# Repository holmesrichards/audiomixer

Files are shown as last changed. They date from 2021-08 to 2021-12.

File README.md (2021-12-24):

# Analog Output Audio Mixer

This is an audio mixer synth module in Kosmo format. It has three inputs, each with a slide attenuator, and a general level control and two identical outputs.

## Current draw
4 mA +12 V, 4 mA -12 V

## Photos

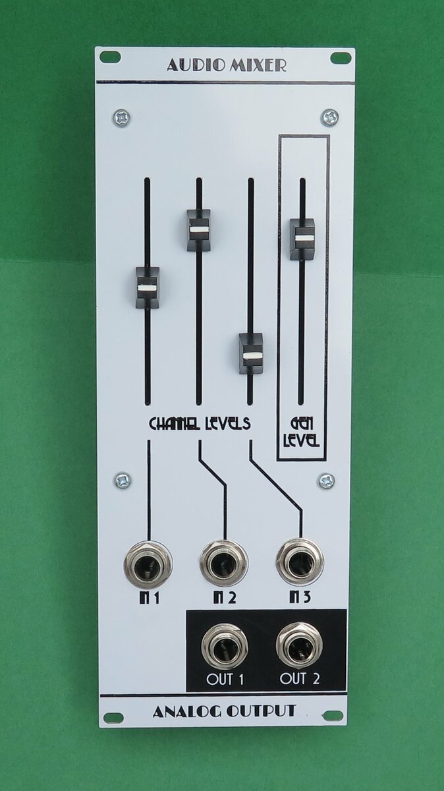
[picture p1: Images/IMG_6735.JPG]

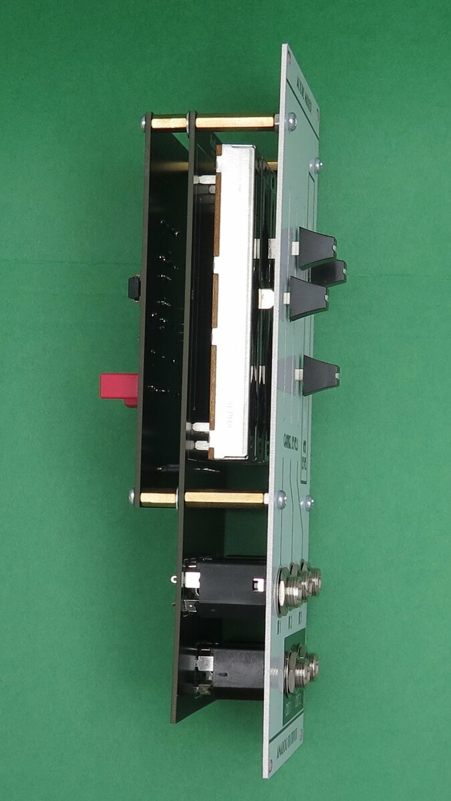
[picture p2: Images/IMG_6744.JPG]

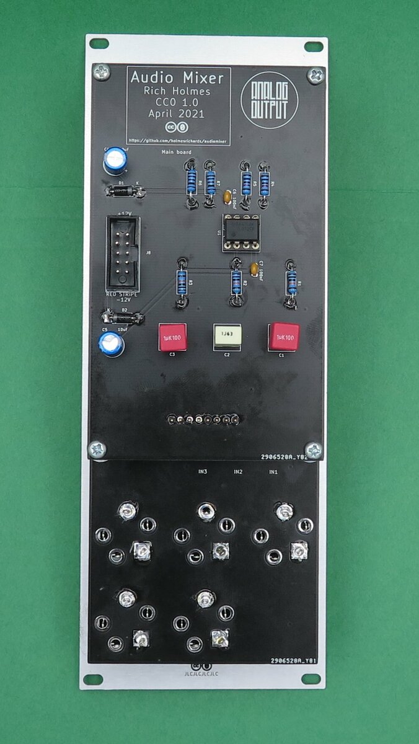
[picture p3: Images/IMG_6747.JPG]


## Documentation:

* [Schematic](Docs/ao_audio_mixer.pdf)
* [PCB layout](Docs/ao_audio_mixer_layout.pdf)
* [BOM](Docs/ao_audio_mixer_bom.md)
* [Build notes](Docs/build.md)

## GitHub repository

* [https://github.com/holmesrichards/audiomixer](https://github.com/holmesrichards/audiomixer)

## Submodules

This repo uses submodules aoKicad and Kosmo_panel, which provide needed libaries for KiCad. To clone:

```
git clone git@github.com:holmesrichards/audiomixer.git
git submodule init
git submodule update
```

Alternatively do

```
git clone --recurse-submodules git@github.com:holmesrichards/audiomixer.git
```

Or if you download the repository as a zip file, you must also click on the "aoKicad" and "Kosmo\_panel" links on the GitHub page (they'll have "@ something" after them) and download them as separate zip files which you can unzip into this repo's aoKicad and Kosmo\_panel directories.

If desired, copy the files from aoKicad and Kosmo\_panel to wherever you prefer (your KiCad user library directory, for instance, if you have one). Then in KiCad, add symbol libraries 

```
aoKicad/ao_symbols
Kosmo_panel/Kosmo
```
and footprint libraries 
```
aoKicad/ao_tht
Kosmo_panel/Kosmo_panel.
```

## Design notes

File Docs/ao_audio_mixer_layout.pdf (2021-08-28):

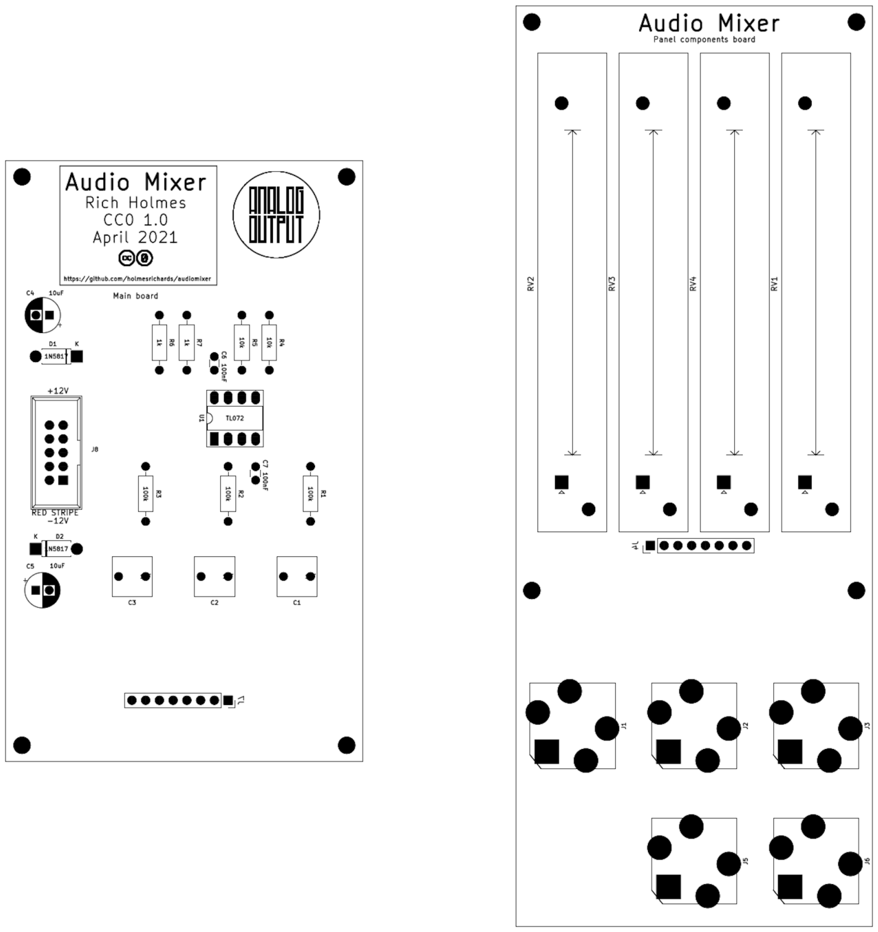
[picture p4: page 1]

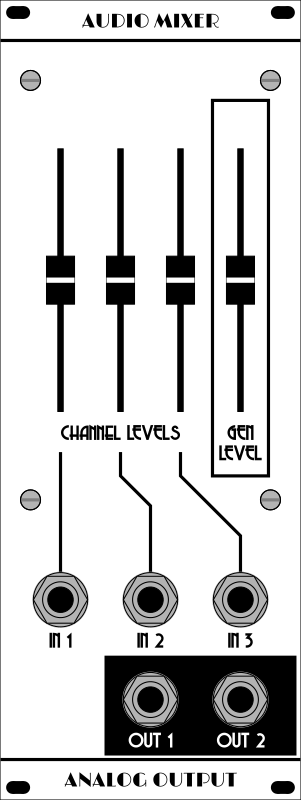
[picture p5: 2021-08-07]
Images/ao_audio_mixer_panel_slide.png

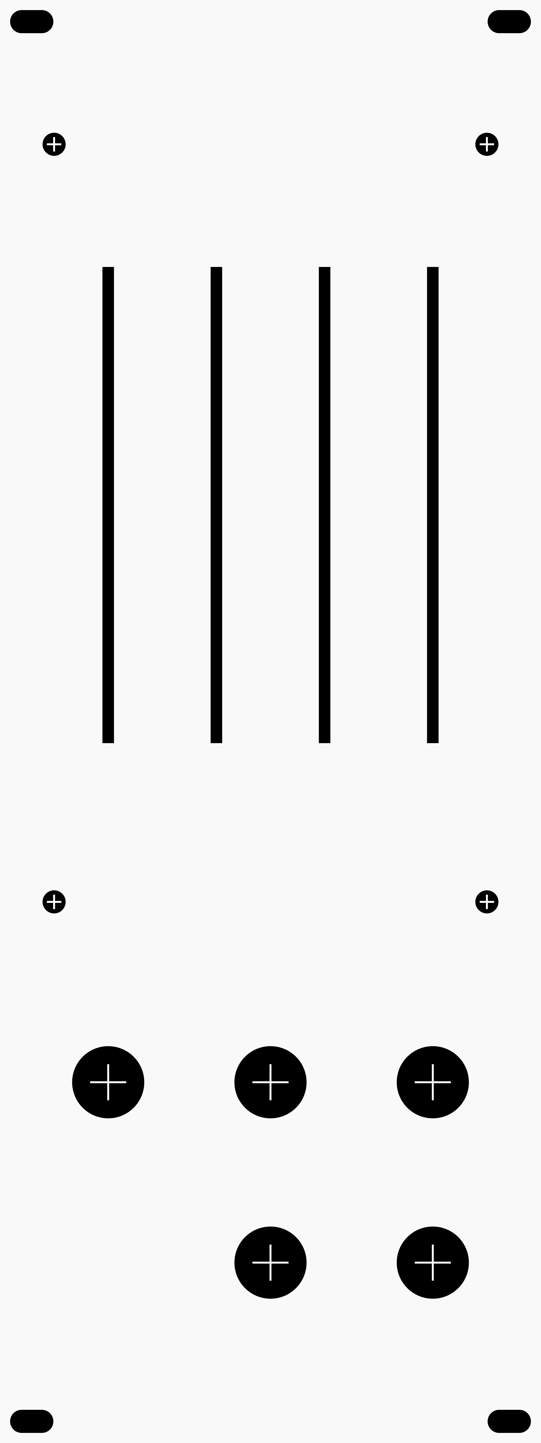
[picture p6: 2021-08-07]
Images/ao_audio_mixer_panel_slide_holes.png

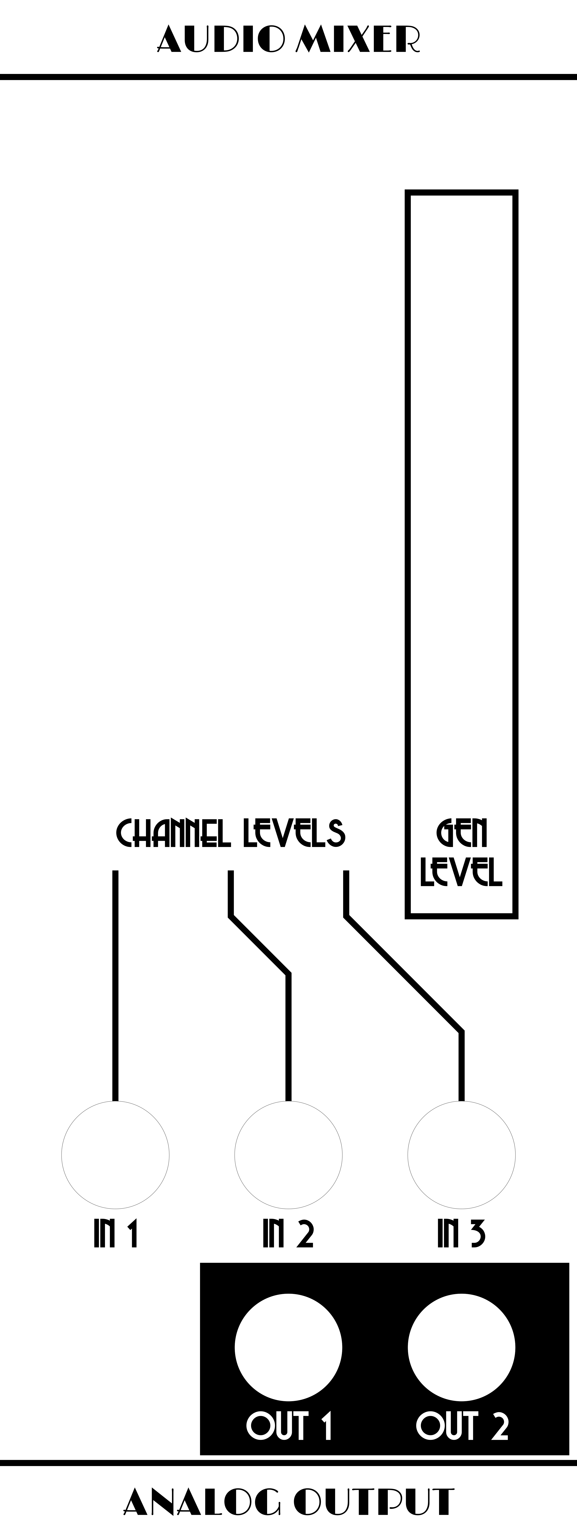
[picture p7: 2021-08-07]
Images/ao_audio_mixer_panel_slide_art.png

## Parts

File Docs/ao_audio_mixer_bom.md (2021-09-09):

# ao_audio_mixer.sch BOM

Sat 28 Aug 2021 09:02:02 AM EDT

Generated from schematic by Eeschema 5.1.10-88a1d61d58~90~ubuntu20.04.1

**Component Count:** 29

| Refs | Qty | Component | Description | Manufacturer | Part | Vendor | SKU |
| ----- | --- | ---- | --- | ---- | ---- | ---- | ---- |
| C1, C2, C3 | 3 | 1uF | Film capacitor |  |  | Tayda | A-4168 |
| C4, C5 | 2 | 10uF | Electrolytic capacitor |  |  | Tayda | A-4349 |
| C6, C7 | 2 | 100nF | Ceramic capacitor |  |  | Tayda | A-553 |
| D1, D2 | 2 | 1N5817 | Schottky diode |  |  | Tayda | A-159 |
| J1, J2, J3, J5, J6 | 5 | AudioJack2 | Audio Jack, 2 Poles (Mono / TS) |  |  | Tayda | A-1121 |
| J4 | 1 | Conn_01x08 | Pin socket 2.54 mm 1x8 |  |  |  |  |
| J7 | 1 | Conn_01x08 | Pin header 2.54 mm 1x8 |  |  |  |  |
| J8 | 1 | Synth_power_2x5 | Pin header 2.54 mm 2x5 |  |  | Tayda | A-2939 |
| R1, R2, R3 | 3 | 100k | Resistor |  |  |  |  |
| R4, R5 | 2 | 10k | Resistor |  |  |  |  |
| R6, R7 | 2 | 1k | Resistor |  |  |  |  |
| RV1, RV2, RV3, RV4 | 4 | A100k | Slide pot | Alpha | RA6020F | Tayda | A-4496 |
| U1 | 1 | TL072 | Dual op amp |  |  | Tayda | A-037 |
| | 1 | | 8 pin DIP socket | | | Tayda | A-001 |
| | 4 | | Slide pot shaft caps | | | | |
| | 4 sets | M3x12 mm | Screws and spacers (see [build notes](Docs/build.md)) | | |  |  |

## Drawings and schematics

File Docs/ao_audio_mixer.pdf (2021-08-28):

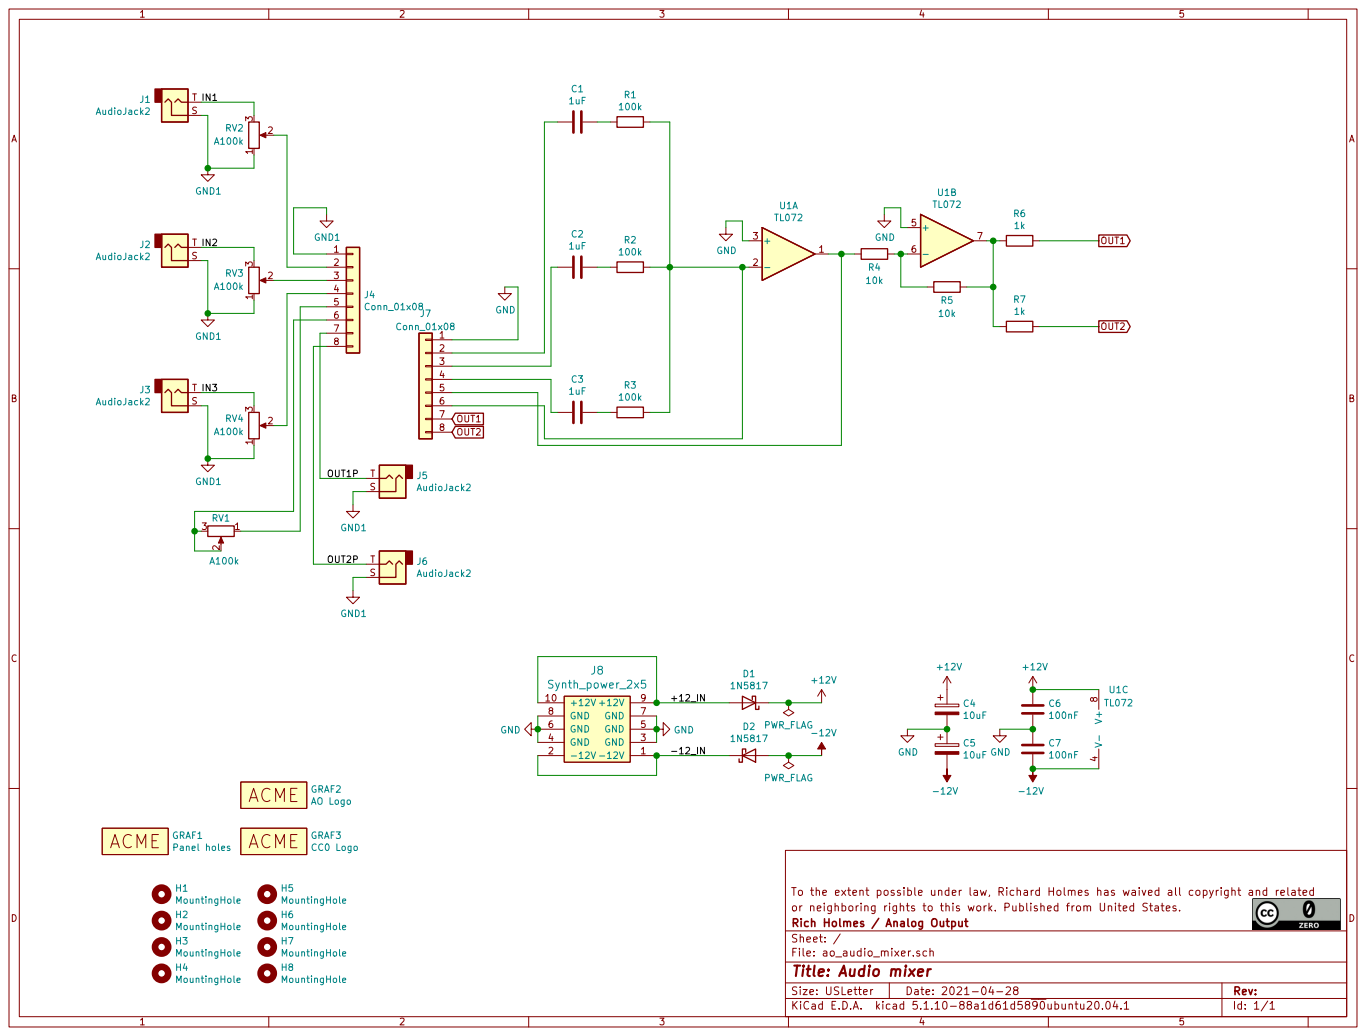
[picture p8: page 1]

3 RV3 A100k ACME GRAF1 Panel holes ACME GRAF3 CC0 Logo

To the extent possible under law, Richard Holmes has waived all copyright and related
or neighboring rights to this work. Published from United States.
File: ao_audio_mixer.sch Sheet: / Rich Holmes / Analog Output

Id: 1/1 Title: Audio mixer

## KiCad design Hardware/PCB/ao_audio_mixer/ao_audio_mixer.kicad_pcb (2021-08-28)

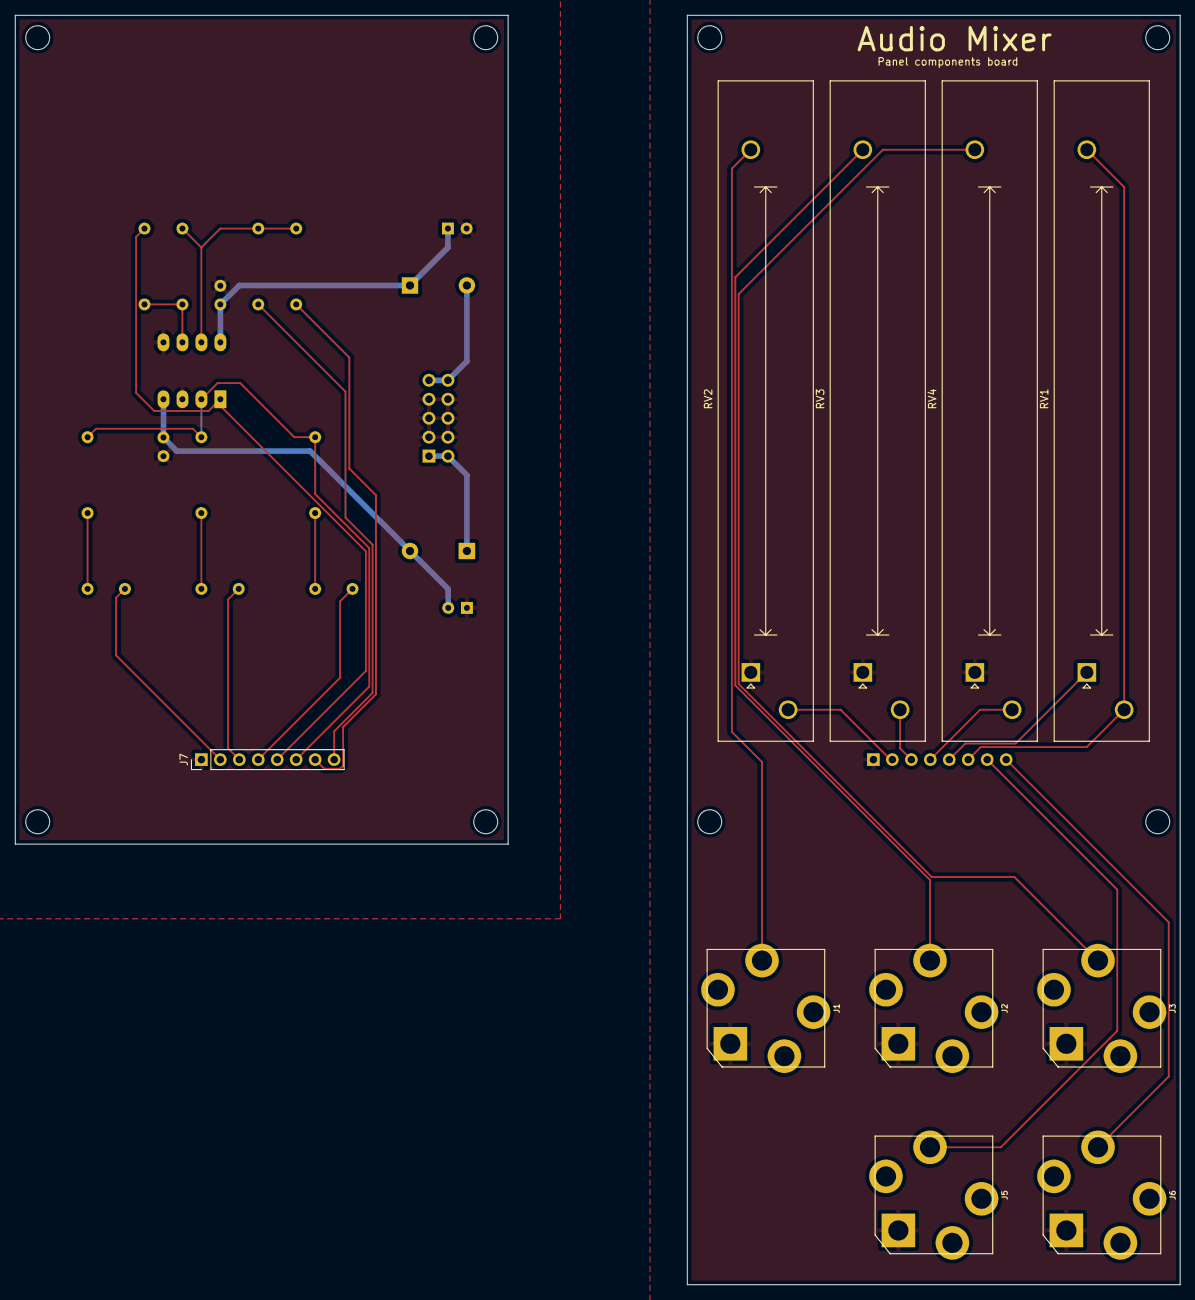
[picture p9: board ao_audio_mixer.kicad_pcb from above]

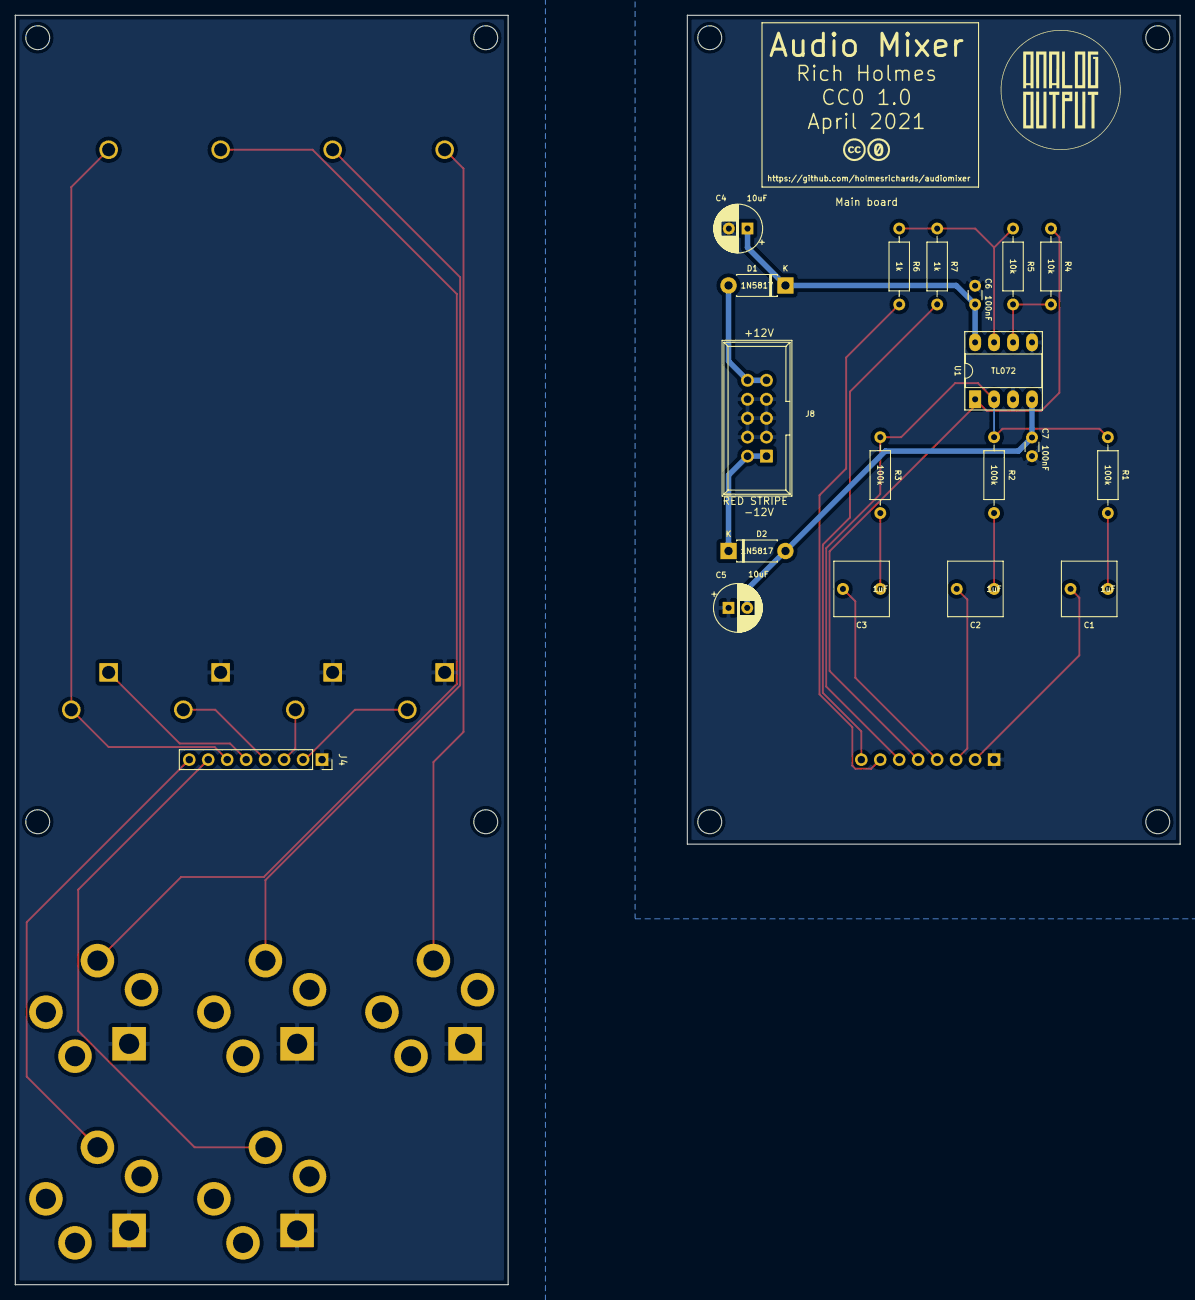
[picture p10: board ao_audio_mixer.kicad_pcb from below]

Board: 2 copper layers, 156.0 x 170.0 mm, 41 parts (25 on the bottom side), 28 nets.

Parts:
C1, C2, C3: 1uF; C_Rect_L7.2mm_W7.2mm_P5.00mm_FKS2_FKP2_MKS2_MKP2
C4, C5: 10uF; CP_Radial_D6.3mm_P2.50mm
C6, C7: 100nF; C_Disc_D3.0mm_W1.6mm_P2.50mm
D1, D2: 1N5817; D_DO-41_SOD81_P7.62mm_Horizontal
GRAF1, GRAF1#2: Panel holes; ao_audio_mixer_panel_slide_holes
GRAF2: AO Logo; analogoutput
GRAF3: CC0 Logo; CC0_logo
H1, H2, H3, H4, H5, H6, H7, H8: MountingHole; MountingHole_3.2mm_M3
J1, J2, J3, J5, J6: AudioJack2; Jack_6.35mm_PJ_629HAN
J4: Conn_01x08; PinSocket_1x08_P2.54mm_Vertical
J7: Conn_01x08; PinHeader_1x08_P2.54mm_Vertical
J8: Synth_power_2x5; Power_Header
R1, R2, R3: 100k; R_Axial_DIN0207_L6.3mm_D2.5mm_P10.16mm_Horizontal
R4, R5: 10k; R_Axial_DIN0207_L6.3mm_D2.5mm_P10.16mm_Horizontal
R6, R7: 1k; R_Axial_DIN0207_L6.3mm_D2.5mm_P10.16mm_Horizontal
RV1, RV2, RV3, RV4: A100k; Potentiometer_Alpha_RA6020F_Single_Slide
U1: TL072; DIP-8_W7.62mm_Socket_LongPads

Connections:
+12V: C4.1, C6.1, D1.1, U1.8
-12V: C5.2, C7.2, D2.2, U1.4
/+12_IN: D1.2, J8.9, J8.10
/-12_IN: D2.1, J8.1, J8.2
/IN1: J1.T, RV2.3
/IN2: J2.T, RV3.3
/IN3: J3.T, RV4.3
/OUT1P: J4.7, J5.T
/OUT2P: J4.8, J6.T
GND: C4.2, C5.1, C6.2, C7.1, J7.1, J8.3, J8.4, J8.5, J8.6, J8.7, J8.8, U1.3, U1.5
GND1: J1.S, J2.S, J3.S, J4.1, J5.S, J6.S, RV2.1, RV3.1, RV4.1
unnamed: C1.1, R1.2
unnamed: C1.2, J7.2
unnamed: C2.1, R2.2
unnamed: C2.2, J7.3
unnamed: C3.1, R3.2
unnamed: C3.2, J7.4
unnamed: J4.2, RV2.2
unnamed: J4.3, RV3.2
unnamed: J4.4, RV4.2
unnamed: J4.5, RV1.1
unnamed: J4.6, RV1.2, RV1.3
unnamed: J7.5, R4.2, U1.1
unnamed: J7.6, R1.1, R2.1, R3.1, U1.2
unnamed: R4.1, R5.2, U1.6
unnamed: R5.1, R6.2, R7.2, U1.7
OUT1: J7.7, R6.1
OUT2: J7.8, R7.1

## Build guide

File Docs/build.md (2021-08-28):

# Analog Output Audio Mixer build notes

## Pots and jacks

To build the pots and jacks board, first position the slide pots on the board, then lay the front panel on top; turn over and solder the pots in place.

Then remove the front panel. Add spacers to the front panel (see below). Position jacks on the board, then put the front panel over the jacks. Loosely secure the jacks with their nuts and washers, and secure the spacers to the PCB, then solder the jacks in place.

## Screws and spacers

Screws and spacers may depend on your choice of jacks and pin headers/sockets, and thickness of panel and PCBs. I used 4 each of:

* 12 mm screw (Tayda A-1253)
* Nut (Tayda A-1247)
* 20 mm male-female spacer (Tayda A-1284)
* Washer (Tayda A-1248)
* 10 mm female-female spacer (Tayda A-1232)
* 6 mm screw (Tayda A-1250)

(All M3.)

12 mm screw through front panel, nut behind panel, 20 mm spacer on screw, pot/jack PCB on spacer; washer behind PCB, 10 mm spacer on 20 mm spacer, main PCB on spacer secured with 6 mm screw.

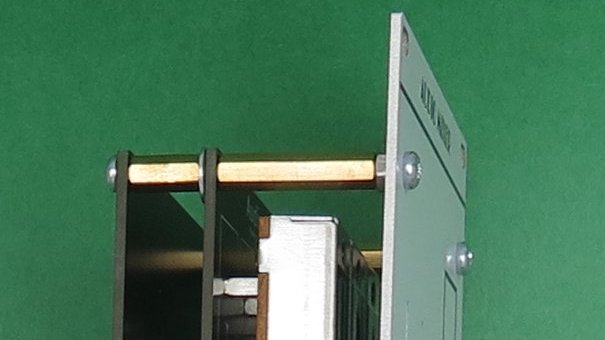
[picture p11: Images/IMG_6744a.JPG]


The bottom two holes in the panel are rather superfluous and could just be left empty or filled with a short screw and nut. Then just secure a spacer between the two PCBs.

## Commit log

2021-08-07 Initial version
    [ao_audio_mixer.kicad_pcb, ao_audio_mixer.sch, ao_audio_mixer_panel.kicad_pcb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]
2021-08-07 Final tweaks before fabbing
    [ao_audio_mixer-B_Cu.gbr, ao_audio_mixer-B_Mask.gbr, ao_audio_mixer-B_Paste.gbr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]
2021-08-12 update kicad_panel
2021-08-12 board mount jacks
    [ao_audio_mixer-B_Cu.gbr, ao_audio_mixer-B_Mask.gbr, ao_audio_mixer-B_Paste.gbr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]
2021-08-16 Restore deleted board
    [ao_audio_mixer.kicad_pcb]
2021-08-21 rm project libraries
    [ao_audio_mixer_panel_al.kicad_pcb, ao_audio_mixer_panel_al.sch]
2021-08-28 Documentation and final fixes before release
    [ao_audio_mixer.kicad_pcb, ao_audio_mixer.sch]
2021-09-09 Clean up libraries, Schottky footprint update
2021-12-24 Current draw
